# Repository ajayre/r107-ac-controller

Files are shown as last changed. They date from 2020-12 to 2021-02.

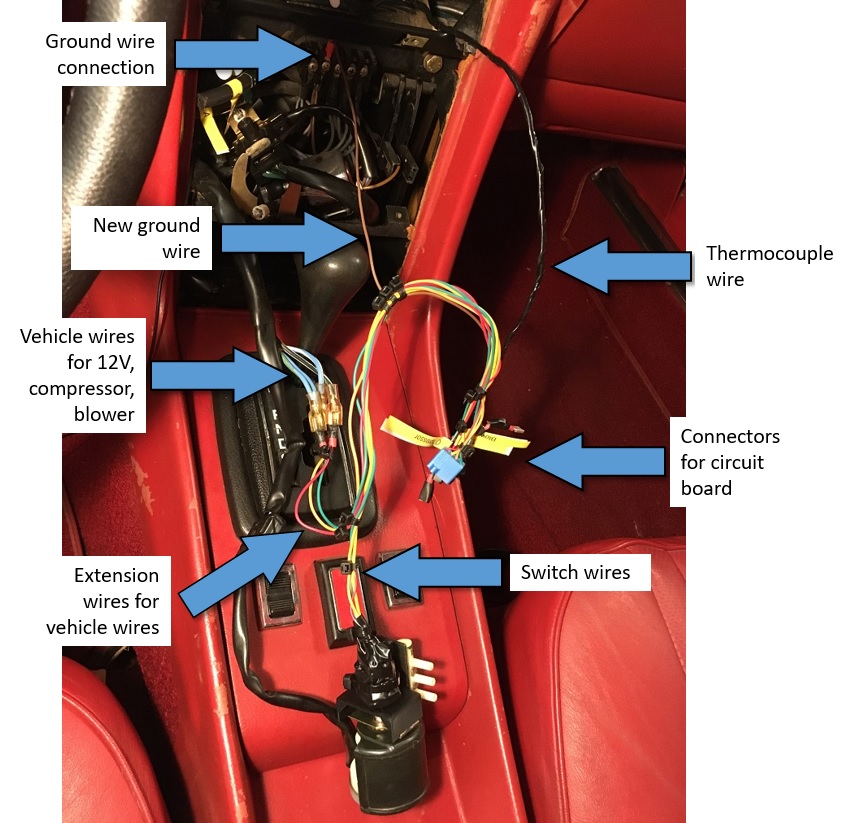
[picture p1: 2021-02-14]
Electronics/Car Wiring Annotated.jpg

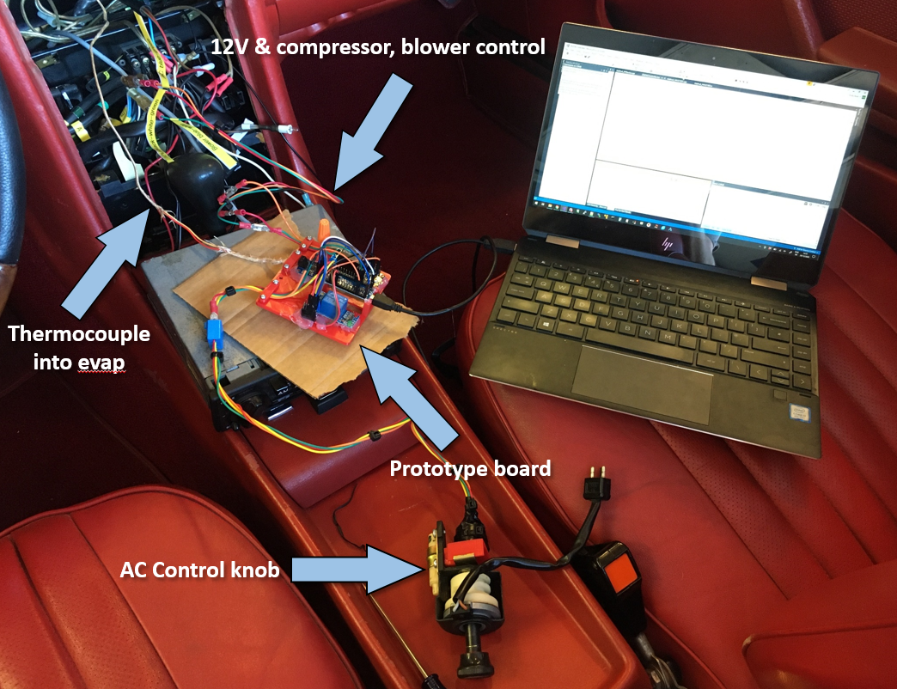
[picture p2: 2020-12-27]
Electronics/Prototyping/Prototype Setup.png

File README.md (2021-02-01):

# R107/C107 Air Conditioning Controller

This is an AC controller for the original Mercedes-Benz R107/C107 manual climate control system. The original system is identified by four vertical levers.

The problem with the AC switch is the delicate capillary tube that senses the evaporator temperature. With age these become brittle and snap off while working on items in the central console. Once broken they are not repairable. Replacements are not available to purchase.

The aim of this project is to replace the Ranco electro-mechanical part of the AC switch with a modern electronic equivalent.

This work is copyright (C) Andrew Ayre 2021 and no commercial use is permitted.

USE AT YOUR OWN RISK. NO WARRANTY, EXPRESS OR IMPLIED.

## Prototype Hardware

The prototype uses the following hardware:

* Arduino Nano - https://www.arduino.cc/en/pmwiki.php?n=Main/ArduinoBoardNano
* Adafruit Thermocouple Amplifier MAX31855 breakout board - https://www.adafruit.com/product/269
* Adafruit Power Relay FeatherWing - https://www.adafruit.com/product/3191

## Development Tools

* Arduino IDE - https://www.arduino.cc/en/software
* Install Microsoft Visual Studio Community Edition 2017 - https://visualstudio.microsoft.com/vs/older-downloads/
* Install Visual Micro - https://marketplace.visualstudio.com/items?itemName=VisualMicro.ArduinoIDEforVisualStudio

## Custom Board

### Programming the Bootloader

Use the Arduino IDE, choose the ATmega328P and your ISP programmer (e.g. USBtinyISP). If you choose to power the board from the programmer then there is no need to provide power via USP or 12V. Connect to the six-pin ISP connector.

### Programming the Firmware

Set the target to 'ATmega328P (Arduino Nano)'.
Connect to the USB connector - it will appear on your PC as a COM port.
Remove the RUN jumper. Replace the jumper after programming.

### LED Operation

The LED will turn on when firmware execution starts. Note that there is a delay of around two or three seconds while the bootloader runs and the LED will be off during this time.

* LED off = power supply problem
* LED on solid = in the 'ready' state, waiting for AC to be turned on. Compressor and blower are off
* LED on with flash off every two seconds = hardware error or corrupted firmware
* LED continually flashing = error
* LED flashing twice = in the 'running' state, blower is on and compressor cycles as needed
* LED flashing three times = in the 'freeze protection' state, blower is on and compressor is off

### RUN Jumper

The RUN jumper should be inserted when the board is installed in a vehicle. It needs to be removed during programming. The purpose of the RUN jumper is to stop noise on the receive line from keeping the board in the bootloader mode and stopping firmware from executing.

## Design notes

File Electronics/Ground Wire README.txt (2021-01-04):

GROUND WIRE
===========

1. Take a length of 20 gauge brown stranded wire

2. At one end crimp a eyelet connector (M4 size?) 22 gauge (red) so it can attach to the screw terminals used for the console lights.

3. At the other end crimp a female quick disconnect connector 0.250" 22 gauge (red).

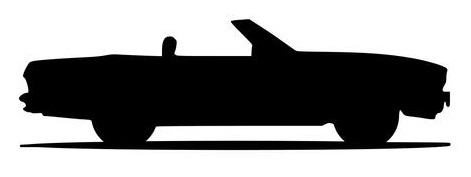
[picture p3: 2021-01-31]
Electronics/PCB/R107Silhouette.jpg

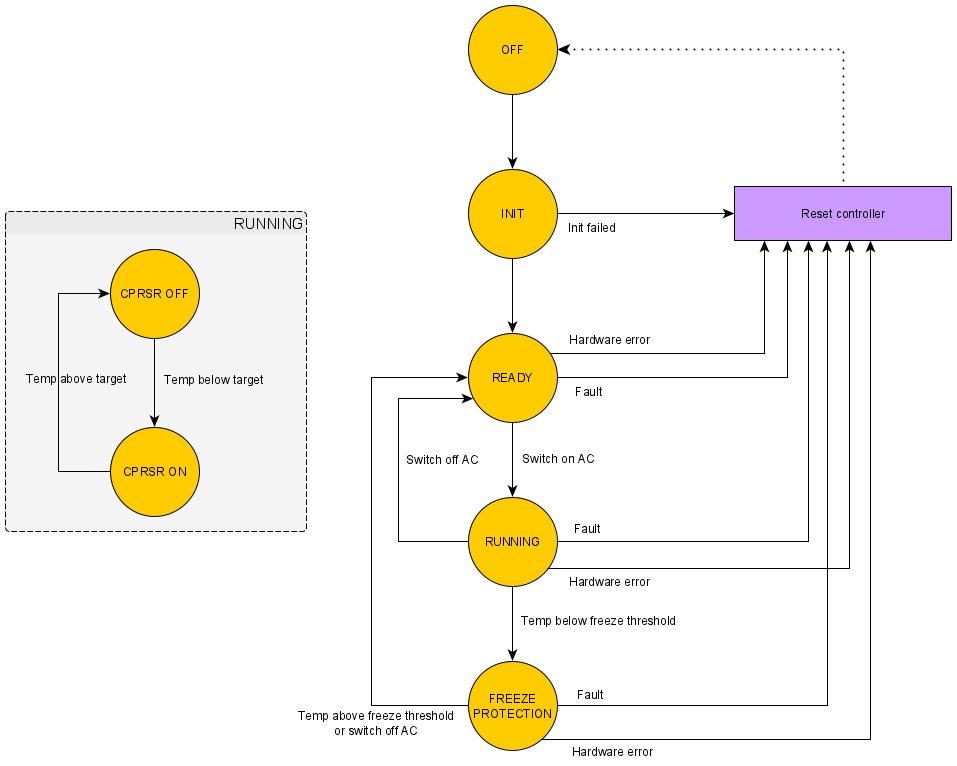
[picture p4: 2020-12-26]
Firmware/Design Documents/State Machine.png

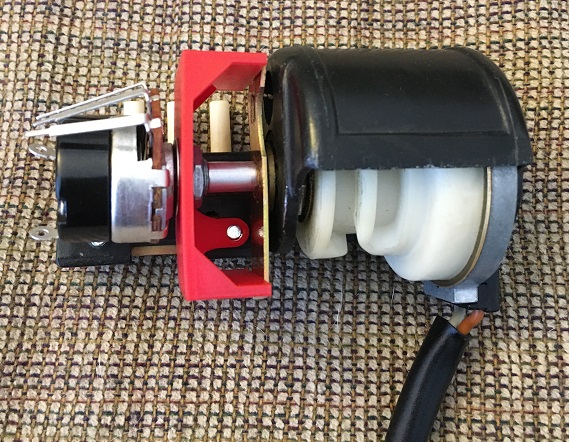
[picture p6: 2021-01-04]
Electronics/Control Knob/Pot.jpg

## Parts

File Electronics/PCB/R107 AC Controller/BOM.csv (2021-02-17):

Manufacturer Part Number | Manufacturer | Digi-Key Part Number | Quantity | Description
690-005-299-043 | EDAC Inc. | 151-1206-1-ND | 1 | CONN RCPT USB2.0 MINI B SMD R/A
ECS-160-18-5PX-TR | ECS Inc. | XC2081CT-ND | 1 | CRYSTAL 16.0000MHZ 18PF SMD
EEE-HA1V4R7R | Panasonic Electronic Components | PCE4248CT-ND | 2 | CAP ALUM 4.7UF 20% 35V SMD
EEE-FK1C681P | Panasonic Electronic Components | PCE3794CT-ND | 1 | CAP ALUM 680UF 20% 16V SMD
EEE-1VA100WR | Panasonic Electronic Components | PCE3948CT-ND | 2 | CAP ALUM 10UF 20% 35V SMD
EEE-FK1C221P | Panasonic Electronic Components | PCE3787CT-ND | 1 | CAP ALUM 220UF 20% 16V SMD
G5LE-14 DC5 | Omron Electronics Inc-EMC Div | Z1011-ND | 2 | RELAY GEN PURPOSE SPDT 10A 5V
MMBT2222ALT1G | ON Semiconductor | MMBT2222ALT1GOSCT-ND | 2 | TRANS NPN 40V 600MA SOT23
ATMEGA328P-AUR | Microchip Technology | ATMEGA328P-AURCT-ND | 1 | IC MCU 8BIT 32KB FLASH 32TQFP
LM2596S-5.0/NOPB | Texas Instruments | LM2596S-5.0/NOPB-ND | 1 | IC REG BUCK 5V 3A TO263-5
MAX31855KASA+T | Maxim Integrated | MAX31855KASA+TCT-ND | 1 | IC CONV THERMOCOUPLE-DGTL SOIC
FT232RL-REEL | FTDI, Future Technology Devices International Ltd | 768-1007-1-ND | 1 | IC USB FS SERIAL UART 28-SSOP
LS T67K-J1L2-1-Z | OSRAM Opto Semiconductors Inc. | 475-2516-1-ND | 1 | LED RED CLEAR 2PLCC SMD
BLM21AG471SH1D | Murata Electronics | 490-11039-1-ND | 2 | FERRITE BEAD 470 OHM 0805 1LN
7804 | Keystone Electronics | 36-7804-ND | 1 | CONN QC TAB 0.250 SOLDER
7802 | Keystone Electronics | 36-7802-ND | 3 | CONN QC TAB 0.250 SOLDER
CL21B104KBCNNNC | Samsung Electro-Mechanics | 1276-1003-1-ND | 4 | CAP CER 0.1UF 50V X7R 0805
CL21B105KOFNNNG | Samsung Electro-Mechanics | 1276-6471-1-ND | 2 | CAP CER 1UF 16V X7R 0805
08055A180JAT2A | AVX Corporation | 478-1307-1-ND | 2 | CAP CER 18PF 50V C0G/NP0 0805
CL21B103KBANNNC | Samsung Electro-Mechanics | 1276-1015-1-ND | 1 | CAP CER 10000PF 50V X7R 0805
MMSD4148T1G | ON Semiconductor | MMSD4148T1GOSCT-ND | 4 | DIODE GEN PURP 100V 200MA SOD123
RNCP0805FTD1K00 | Stackpole Electronics Inc | RNCP0805FTD1K00CT-ND | 7 | RES 1K OHM 1% 1/4W 0805
RNCP0805FTD10K0 | Stackpole Electronics Inc | RNCP0805FTD10K0CT-ND | 4 | RES 10K OHM 1% 1/4W 0805
B360A-13-F | Diodes Incorporated | B360A-FDICT-ND | 1 | DIODE SCHOTTKY 60V 3A SMA
MBR0520LT1G | ON Semiconductor | MBR0520LT1GOSCT-ND | 1 | DIODE SCHOTTKY 20V 500MA SOD123

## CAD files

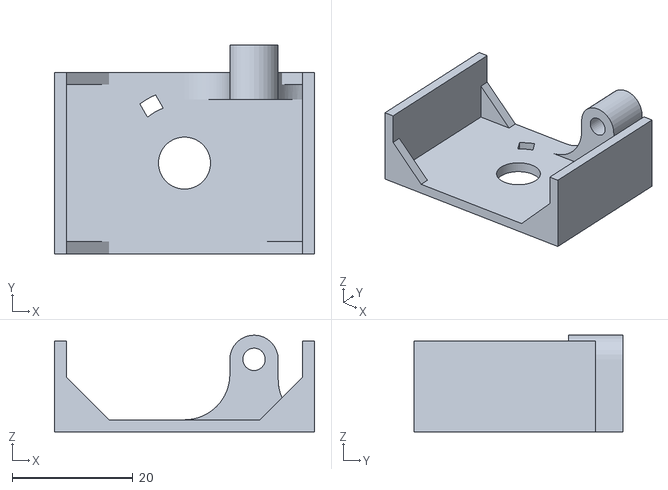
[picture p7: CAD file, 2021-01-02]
Mechanical/CAD/Pot Bracket.stl
43.0 x 34.5 x 16.0

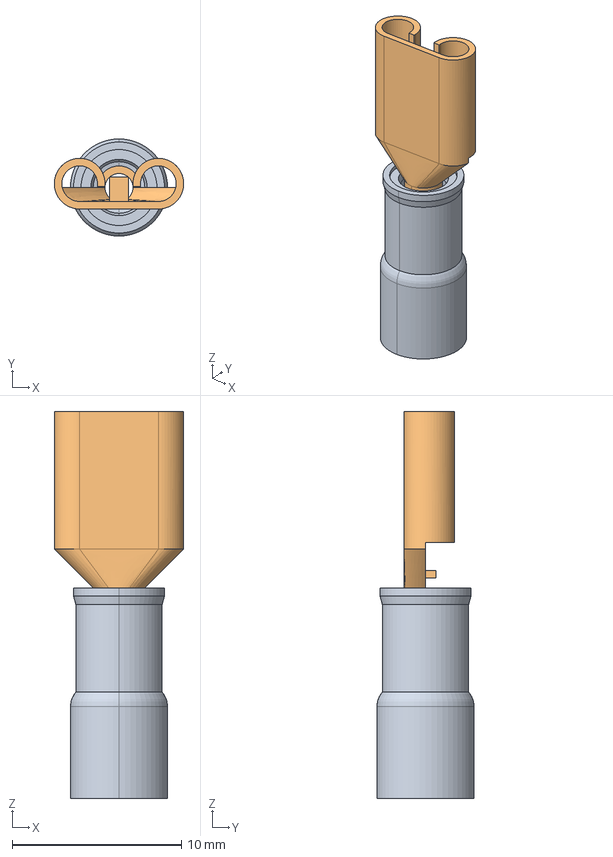
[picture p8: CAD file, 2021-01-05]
Mechanical/Case/c-0640903-81-j1-3d.stp
7.64 x 5.74 x 22.9 mm

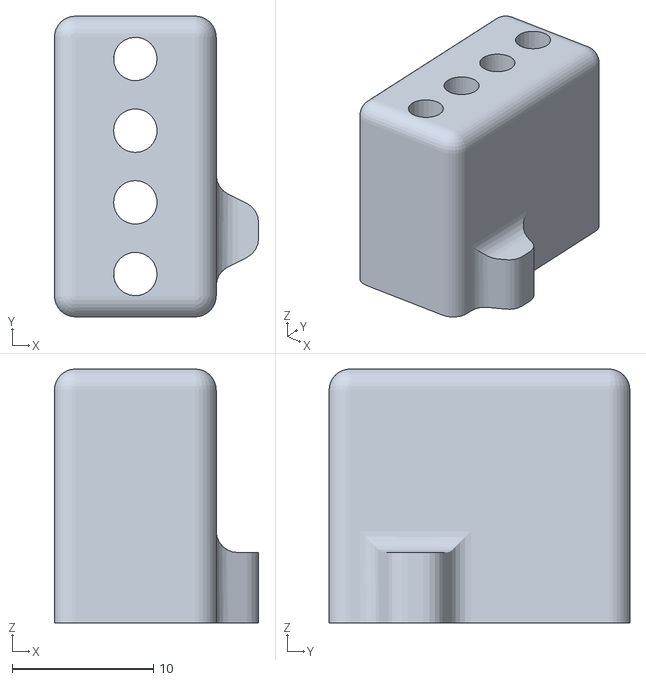
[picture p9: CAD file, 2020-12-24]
Mechanical/CAD/Four Pin Connector.stl
14.5 x 21.3 x 18.0

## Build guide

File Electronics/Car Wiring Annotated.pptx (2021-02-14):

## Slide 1

Ground wire connection

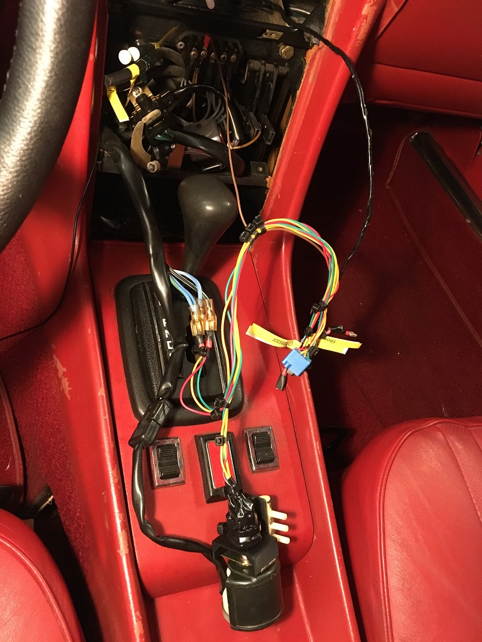
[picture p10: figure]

New ground wire

Vehicle wires for 12V, compressor, blower

Thermocouple wire

Switch wires

Connectors for circuit board

Extension wires for vehicle wires

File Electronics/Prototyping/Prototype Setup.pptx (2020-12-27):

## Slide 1

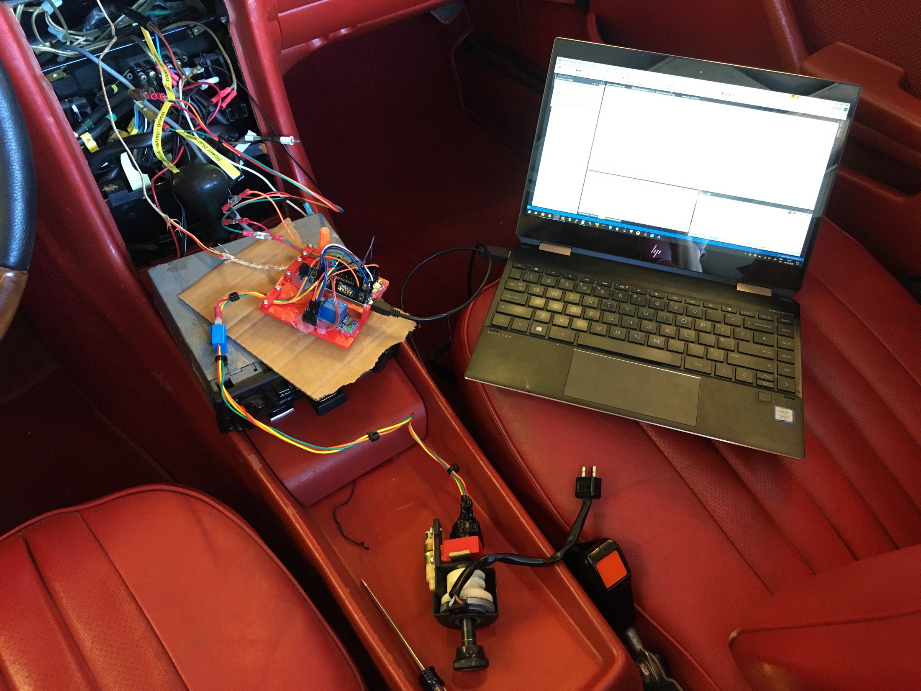
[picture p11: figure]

12V & compressor, blower control

Thermocouple
into evap

Prototype board

AC Control knob

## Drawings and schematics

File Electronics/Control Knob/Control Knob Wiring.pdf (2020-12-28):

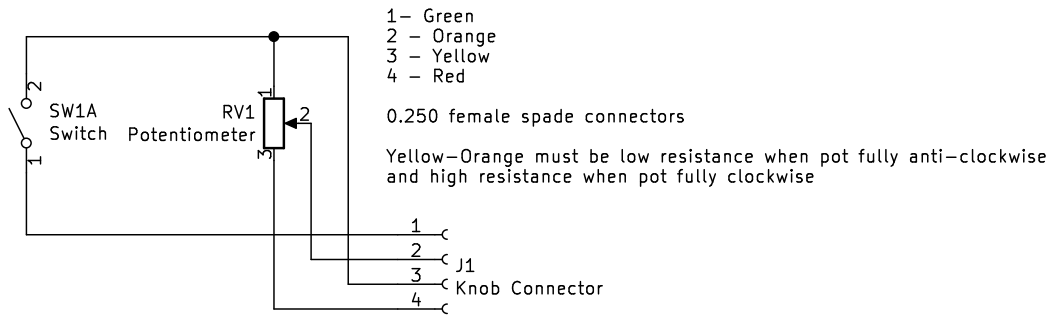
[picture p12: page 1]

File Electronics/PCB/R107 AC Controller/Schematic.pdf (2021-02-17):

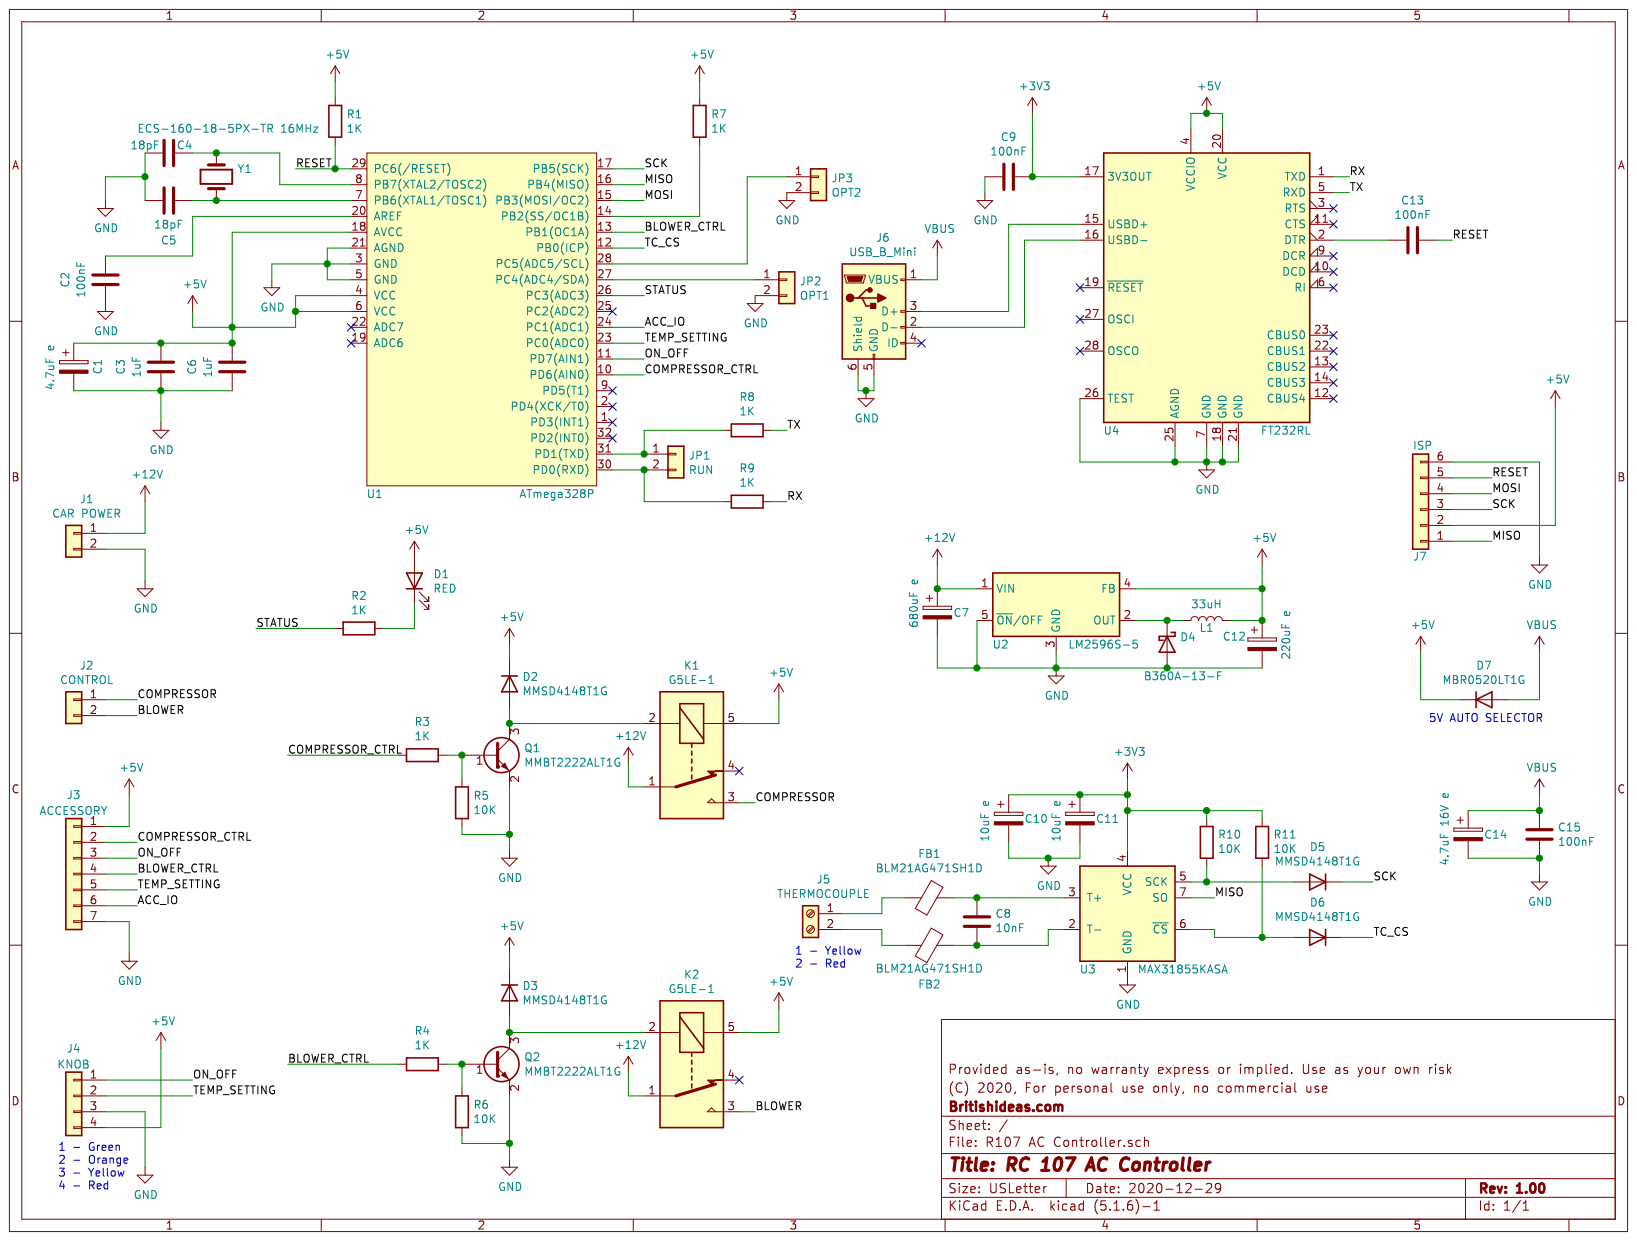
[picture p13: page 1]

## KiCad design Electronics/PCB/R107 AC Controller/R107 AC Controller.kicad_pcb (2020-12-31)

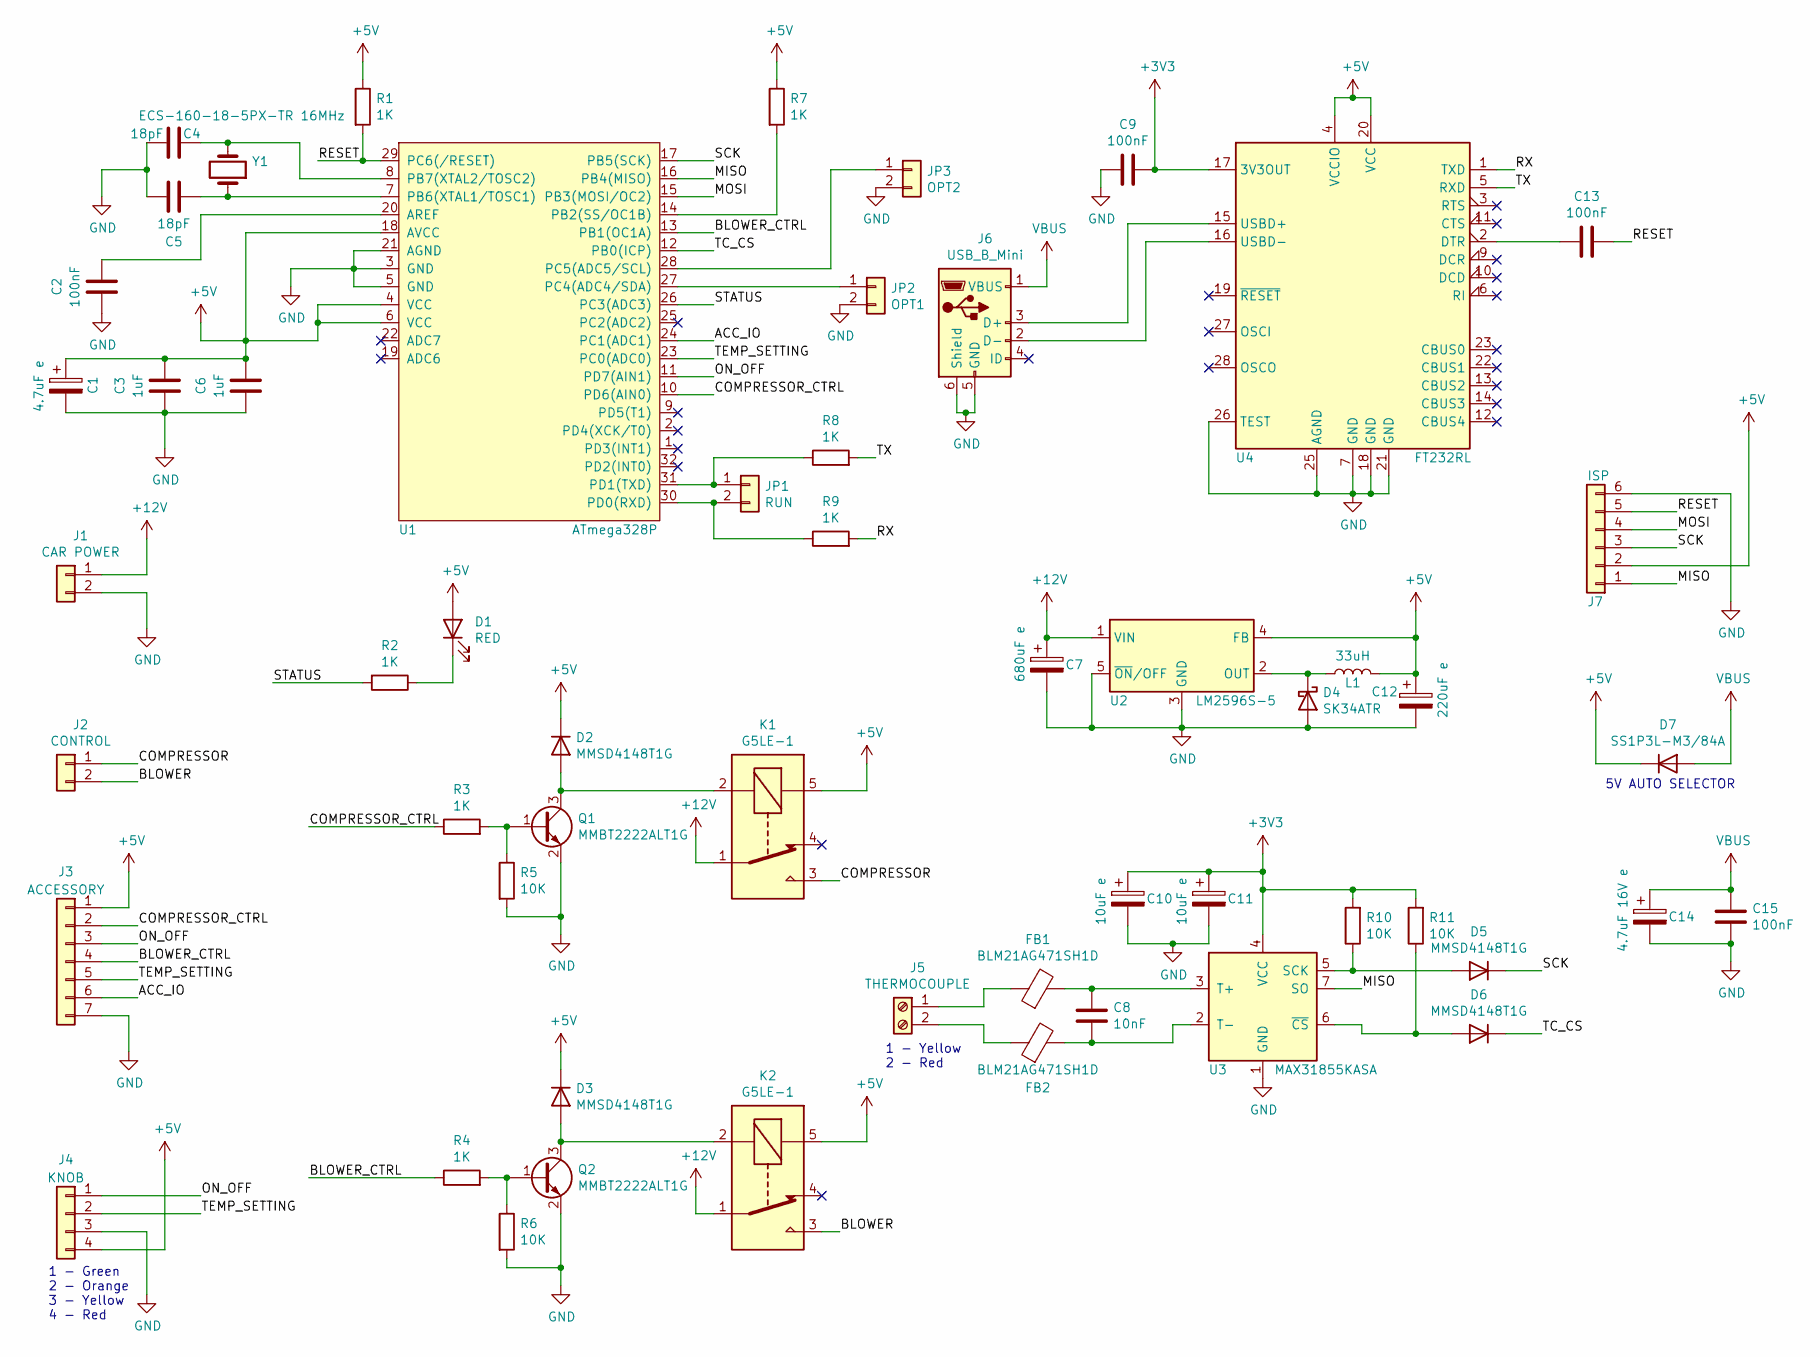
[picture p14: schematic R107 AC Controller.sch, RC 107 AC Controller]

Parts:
C1: 4.7uF e; CP_Elec_4x5.8
C2, C9, C13, C15: 100nF; C_0805_2012Metric
C3, C6: 1uF; C_0805_2012Metric
C4, C5: 18pF; C_0805_2012Metric
C7: 680uF e; CP_Elec_10x10.5
C8: 10nF; C_0805_2012Metric
C10, C11: 10uF e; CP_Elec_4x5.4
C12: 220uF e; CP_Elec_8x6.5
C14: 4.7uF 16V e; CP_Elec_4x5.8
D1: RED; LED_PLCC-2
D2, D3, D5, D6: MMSD4148T1G; D_SOD-123
D4: SK34ATR; D_SMA
D7: SS1P3L-M3/84A; SMP_DO-220AA
FB1, FB2: BLM21AG471SH1D; L_0805_2012Metric
J1: CAR POWER; Keystone_SturdiMount_TabConnector_1x2
J2: CONTROL; Keystone_SturdiMount_TabConnector_1x2
J3: ACCESSORY; PinHeader_1x07_P2.54mm_Vertical
J4: KNOB; Keystone_SturdiMount_TabConnector_1x4
J5: THERMOCOUPLE; TerminalBlock_TE_282834-2_1x02_P2.54mm_Horizontal
J6: USB_B_Mini; USB_Mini-B_Wuerth_65100516121_Horizontal
J7: ISP; PinHeader_2x03_P2.54mm_Vertical
JP1: RUN; PinHeader_1x02_P2.54mm_Vertical
JP2: OPT1; PinHeader_1x02_P2.54mm_Vertical
JP3: OPT2; PinHeader_1x02_P2.54mm_Vertical
K1, K2: G5LE-1; Relay_SPDT_Omron-G5LE-1
L1: 33uH; Chilisin_Power_Inductor_AWVS_808040
Q1, Q2: MMBT2222ALT1G; SOT-23
R1, R2, R3, R4, R7, R8, R9: 1K; R_0805_2012Metric
R5, R6, R10, R11: 10K; R_0805_2012Metric
U1: ATmega328P; LQFP-32_7x7mm_P0.8mm
U2: LM2596S-5; TO-263-5_TabPin3
U3: MAX31855KASA; SOIC-8_3.9x4.9mm_P1.27mm
U4: FT232RL; SSOP-28_5.3x10.2mm_P0.65mm
Y1: ECS-160-18-5PX-TR 16MHz; HC-49_US

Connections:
+3V3: C9.1, C10.1, C11.1, R10.2, R11.2, U3.4 (VCC), U4.17 (3V3OUT)
+5V: C1.1, C3.1, C6.1, C12.1, D1.2 (A), D2.1 (K), D3.1 (K), D7.1 (K), J3.1, J4.4, J7.2, K1.5, K2.5, L1.2, R1.1, R7.1, U1.4 (VCC), U1.6 (VCC), U1.18 (AVCC), U2.4 (FB), U4.4 (VCCIO), U4.20 (VCC)
+12V: C7.1, J1.1, K1.1, K2.1, U2.1 (VIN)
/ACC_IO: J3.6, U1.24 (PC1(ADC1))
/BLOWER: J2.2, K2.3
/BLOWER_CTRL: J3.4, R4.1, U1.13 (PB1(OC1A))
/COMPRESSOR: J2.1, K1.3
/COMPRESSOR_CTRL: J3.2, R3.1, U1.10 (PD6(AIN0))
/MISO: J7.1, U1.16 (PB4(MISO)), U3.7 (SO)
/MOSI: J7.4, U1.15 (PB3(MOSI/OC2))
/ON_OFF: J3.3, J4.1, U1.11 (PD7(AIN1))
/RESET: C13.1, J7.5, R1.2, U1.29 (PC6(/RESET))
/RX: R9.2, U4.1 (TXD)
/SCK: D5.1 (K), J7.3, U1.17 (PB5(SCK))
/STATUS: R2.2, U1.26 (PC3(ADC3))
/TC_CS: D6.1 (K), U1.12 (PB0(ICP))
/TEMP_SETTING: J3.5, J4.2, U1.23 (PC0(ADC0))
/TX: R8.2, U4.5 (RXD)
GND: C1.2, C2.2, C3.2, C4.2, C5.1, C6.2, C7.2, C9.2, C10.2, C11.2, C12.2, C14.2, C15.2, D4.2 (A), J1.2, J3.7, J4.3, J6.5 (GND), J6.6 (Shield), J7.6, JP2.2, JP3.2, Q1.2 (E), Q2.2 (E), R5.2, R6.2, U1.3 (GND), U1.5 (GND), U1.21 (AGND), U2.3 (GND), U2.5 (~ON~/OFF), U3.1 (GND), U4.7 (GND), U4.18 (GND), U4.21 (GND), U4.25 (AGND), U4.26 (TEST)
unnamed: C2.1, U1.20 (AREF)
unnamed: C4.1, U1.8 (PB7(XTAL2/TOSC2)), Y1.2
unnamed: C5.2, U1.7 (PB6(XTAL1/TOSC1)), Y1.1
unnamed: C8.1, FB2.2, U3.2 (T-)
unnamed: C8.2, FB1.2, U3.3 (T+)
unnamed: C13.2, U4.2 (DTR)
unnamed: D1.1 (K), R2.1
unnamed: D2.2 (A), K1.2, Q1.3 (C)
unnamed: D3.2 (A), K2.2, Q2.3 (C)
unnamed: D4.1 (K), L1.1, U2.2 (OUT)
unnamed: D5.2 (A), R10.1, U3.5 (SCK)
unnamed: D6.2 (A), R11.1, U3.6 (~CS~)
unnamed: FB1.1, J5.1
unnamed: FB2.1, J5.2
unnamed: J6.2 (D-), U4.16 (USBD-)
unnamed: J6.3 (D+), U4.15 (USBD+)
unnamed: JP1.1, R8.1, U1.31 (PD1(TXD))
unnamed: JP1.2, R9.1, U1.30 (PD0(RXD))
unnamed: JP2.1, U1.27 (PC4(ADC4/SDA))
unnamed: JP3.1, U1.28 (PC5(ADC5/SCL))
unnamed: Q1.1 (B), R3.2, R5.1
unnamed: Q2.1 (B), R4.2, R6.1
unnamed: R7.2, U1.14 (PB2(SS/OC1B))
VBUS: C14.1, C15.1, D7.2 (A), J6.1 (VBUS)

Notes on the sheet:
5V AUTO SELECTOR
1 - Green 2 - Orange 3 - Yellow 4 - Red
1 - Yellow 2 - Red

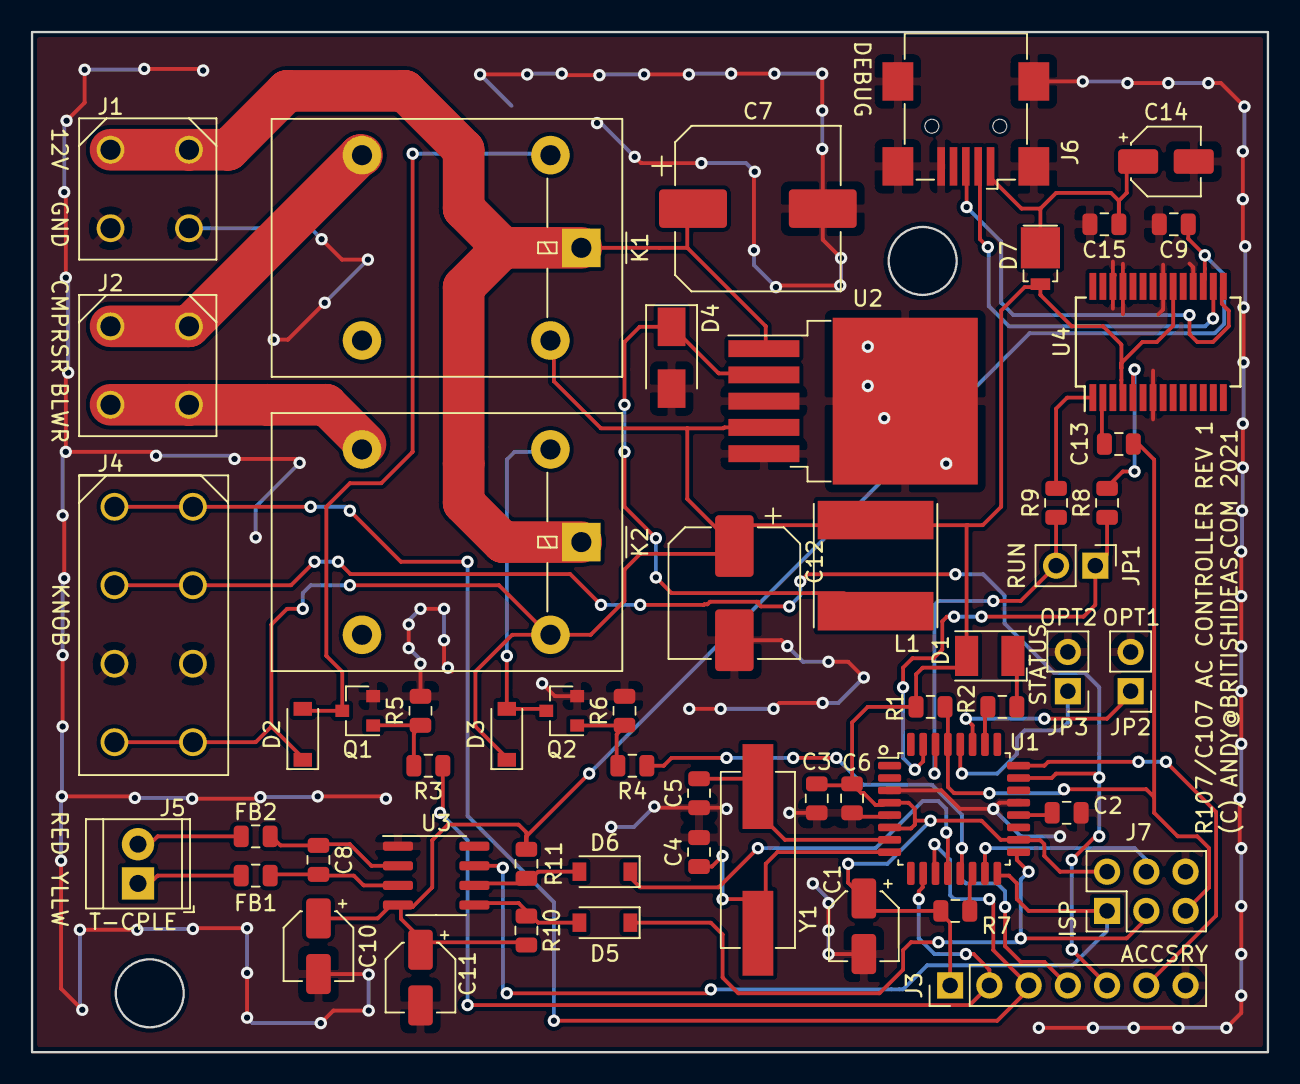
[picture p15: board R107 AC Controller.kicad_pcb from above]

Board: 2 copper layers, 80.0 x 66.0 mm, 55 parts (0 on the bottom side), 43 nets.

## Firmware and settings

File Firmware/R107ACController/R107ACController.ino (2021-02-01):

// R107/C107 AC Controller (manual climate control)
// (C) Andy Ayre, 2021, all rights reserved, no commercial usage
// https://github.com/ajayre/r107-ac-controller
// Outputs to serial port at 57,600 baud

#include "src/Adafruit-MAX31855/Adafruit_MAX31855.h"
#include <avr/wdt.h>

// the version of this firmware
#define VERSION "1.00"

// define to 1 to simulate ac instead of reading thermocouple
#define SIMULATE_AC 0

// logic
#define FALSE (0)
#define TRUE (!FALSE)

// minimum evap temperature in celcius
// below this the freeze protection will start
#define MINIMUM_TEMPERATURE 2.0F
// the number of degrees in celcius the evap temp has to rise before
// exiting freeze protection
#define FREEZEPROTECTION_HYSTERESIS 1.0F
// the number of degrees in celcius the eval temp has to rise before
// turning compressor back on after reaching target
// larger value = worse performance of system
// smaller value = more cycling of compressor on/off when at target
#define TEMP_HYSTERESIS 1.0F
// size of temperature range controllable by user, in degrees celcius
#define TEMP_RANGE 15.0F

// pin to control the compressor
#define COMPRESSOR      6    // D6
// pin for on/off switch
#define CONTROL_SWITCH  7    // D7
// thermocouple chip select (uses hardware SPI)
#define CS_THERMOCOUPLE 8    // D8
// pin to control the blower motor
#define BLOWER_MOTOR    9    // D9
// pin for temperature control (analog)
#define TEMP_SETTING    A0
// pin for status LED
#define STATUS_LED      A3
// pin for opt 1
#define OPT1            A4
// pin for opt 2
#define OPT2            A5

// thermocouple errors
#define THERMOCOUPLE_ERROR_SCV 0x04 // short circuit to vcc
#define THERMOCOUPLE_ERROR_SCG 0x02 // short circuit to ground
#define THERMOCOUPLE_ERROR_OC  0x01 // open connection

// status LED control
#define STATUS_LED_ON  digitalWrite(STATUS_LED, LOW)
#define STATUS_LED_OFF digitalWrite(STATUS_LED, HIGH);
#define IS_STATUS_LED_ON (digitalRead(STATUS_LED) == 1 ? FALSE : TRUE)

// blower control macros (connect to NO on relay)
#define BLOWER_OFF digitalWrite(BLOWER_MOTOR, LOW); Serial.println("Blower off");
#define BLOWER_ON  digitalWrite(BLOWER_MOTOR, HIGH); Serial.println("Blower on");
#define IS_BLOWER_ON digitalRead(BLOWER_MOTOR)

// compressor control macros (connect to NO on relay)
#define COMPRESSOR_OFF digitalWrite(COMPRESSOR, LOW); Serial.println("Compressor off")
#define COMPRESSOR_ON  digitalWrite(COMPRESSOR, HIGH); Serial.println("Compressor on")
#define IS_COMPRESSOR_ON digitalRead(COMPRESSOR)

// control switch macro
// returns 0 for off, 1 for on
#define GET_CONTROL_SWITCH (!(digitalRead(CONTROL_SWITCH) & 0x01))

// temp setting macro
// returns 0 = min, 1023 = max
#define RAW_TEMP_SETTING analogRead(TEMP_SETTING)
// raw temp setting where switch moves from fresh air to inside air
#define RAW_INSIDE_AIR_THRESHOLD 800
// scaled temp setting threshold
#define INSIDE_AIR_THRESHOLD (RAW_INSIDE_AIR_THRESHOLD / 1023.0F * 100.0F)

// minimum on or off time in milliseconds
#define LED_PERIOD 200
// time between patterns as a multiple of LED_PERIOD
#define LED_PATTERN_OFF_TIME 4

// pattern to show on LED in the various state machine states
#define LED_PATTERN_RUNNING          2
#define LED_PATTERN_FREEZEPROTECTION 3

// time between updates of debug output in milliseconds
#define DEBUG_OUTPUT_PERIOD 500

// number of evap temperature readings to use for averaging
// larger number = more smoothing, lower number = faster response to changes
#define AVERAGING_NUM_EVAP_READINGS 256

// never use simulation for release builds
#if _DEBUG == 0
#undef SIMULATE_AC
#define SIMULATE_AC 0
#endif // _DEBUG == 0

// ac state machine states
typedef enum _acstates
{
  OFF,
  INIT,
  READY,
  RUNNING,
  FREEZEPROTECTION
} ACSTATE;

// modes of operation for the LED
typedef enum _ledmodes
{
  LED_Mode_Off,
  LED_Mode_On,
  LED_Mode_Error,
  LED_Mode_Pattern
} LEDMODES;

// the states used to flash patterns on the LED
typedef enum _ledpatternstates
{
  LED_Pattern_Flashing,
  LED_Pattern_Paused
} LEDPATTERNSTATES;

// access to thermocouple
static Adafruit_MAX31855 Thermocouple(CS_THERMOCOUPLE);
// current ac state
static ACSTATE ACState = OFF;

// timestamp for debug output
static unsigned long NextDebugOutputTime;

// averaging of temperature
static double EvapTemperatureAverageN;
static int EvapTemperatureValid;
static int EvapTemperatureReadings;

// LED handling
static LEDMODES LEDMode;
static unsigned long LEDNextTime;
static int LEDPatternCounter;
static LEDPATTERNSTATES LEDPatternState;
static int LEDPatternNumber;

#if SIMULATE_AC == 1
static unsigned long SimulationTimestamp = 0;
static double SimulatedTemp = -1;
static double GetSimulatedTemperature
  (
  double AmbientTemperature
  )
{
  // don't do anything until one second has passed
  if (millis() - SimulationTimestamp < 1000)
  {
    return;
  }

  SimulationTimestamp = millis();

  // set starting temp for simulation
  if (SimulatedTemp < 0) SimulatedTemp = AmbientTemperature;

  // if compressor is on then decrease temp 6 deg C per min
  if (IS_COMPRESSOR_ON)
  {
    SimulatedTemp -= 0.1;
    if (SimulatedTemp < 0) SimulatedTemp = 0;
  }
  // if compressor is off then increase temp 6 deg C per min
  else
  {
    SimulatedTemp += 0.1;
    if (SimulatedTemp > AmbientTemperature) SimulatedTemp = AmbientTemperature;
  }

  return SimulatedTemp;
}
#endif // SIMULATE_AC == 1

// Starts flashing a pattern on the LED
static void EnableLEDPattern
  (
  int PatternNumber                  // number of flashes before pausing
  )
{
  LEDMode = LED_Mode_Pattern;
  LEDNextTime = GetTime() + LED_PERIOD;
  LEDPatternCounter = 0;
  LEDPatternState = LED_Pattern_Flashing;
  LEDPatternNumber = PatternNumber;
  STATUS_LED_OFF;
}

// Gets the current time in milliseconds since last power on
static unsigned long GetTime
  (
  void
  )
{
  return millis();
}

// Checks if a timestamp is in the past, handles 32-bit timer overflow
static uint8_t IsTimeExpired
  (
  unsigned long timestamp            // timestamp to check
  )
{
  unsigned long time_now;

  time_now = millis();
  if (time_now >= timestamp)
  {
    if ((time_now - timestamp) < 0x80000000)
      return 1;
    else
      return 0;
  }
  else
  {
    if ((timestamp - time_now) >= 0x80000000)
      return 1;
    else
      return 0;
  }
}

// Call frequently to update the LED
static void LEDHandler
  (
  void
  )
{
  if (IsTimeExpired(LEDNextTime))
  {
    switch (LEDMode)
    {
      // turn LED off
    case LED_Mode_Off:
      STATUS_LED_OFF;
      break;

      // turn LED on
    case LED_Mode_On:
      STATUS_LED_ON;
      break;

      // show the error state on the LED
    case LED_Mode_Error:
      if (IS_STATUS_LED_ON)
      {
        STATUS_LED_OFF;
      }
      else
      {
        STATUS_LED_ON;
      }
      break;

      // show a specific pattern on the LED
    case LED_Mode_Pattern:
      switch (LEDPatternState)
      {
      case LED_Pattern_Flashing:
        if (IS_STATUS_LED_ON)
        {
          STATUS_LED_OFF;
        }
        else
        {
          STATUS_LED_ON;
          if (++LEDPatternCounter == LEDPatternNumber)
          {
            LEDPatternState = LED_Pattern_Paused;
            LEDPatternCounter = 0;
          }
        }
        break;

      case LED_Pattern_Paused:
        STATUS_LED_OFF;
        if (++LEDPatternCounter == LED_PATTERN_OFF_TIME)
        {
          LEDPatternState = LED_Pattern_Flashing;
          LEDPatternCounter = 0;
        }
        break;
      }
      break;
    }

    LEDNextTime = GetTime() + LED_PERIOD;
  }
}

// calculates the target evap temperature based on the current setting
// and measurements
// note - if TempSetting is greater than INSIDE_AIR_THRESHOLD then the
// switch is in the 'inside' range
// returns the target evap temperature in degrees C
// note - return value must be at least MINIMUM_TEMPERATURE
static double GetTargetEvapTemperature
(
  double TempSetting,                           // user's temp setting 0 (min) -> 100 (max)
  double AmbientTemperature,                    // in degrees C, taken from behind dashboard, NOT equal to outside temp
  double EvapTemperature,                       // in degrees C
  int OutputDebugData                           // TRUE to allow output of debug data
  )
{
  if (OutputDebugData)
  {
    Serial.print("Knob setting % = ");
    Serial.print(TempSetting);
    if (TempSetting > INSIDE_AIR_THRESHOLD)
      Serial.println(" (inside)");
    else
      Serial.println(" (fresh air)");
  }

  // get controllable temperarure range
  double MinTemp = MINIMUM_TEMPERATURE;
  double MaxTemp = MinTemp + TEMP_RANGE;

  // scale the user's temperature setting over the min -> max range
  double TargetTemperature = MaxTemp - ((MaxTemp - MinTemp) * (TempSetting / 100.0));

  return TargetTemperature;
}

// the setup function runs once when you press reset or power the board
void setup
  (
  void
  )
{
  int opt1, opt2;

#if _DEBUG == 0
  // enable watchdog timer with two second timeout
  wdt_enable(WDTO_2S);
#endif

  // configure status LED and turn on
  pinMode(STATUS_LED, OUTPUT);
  // turn LED on
  LEDMode = LED_Mode_On;

  // start serial output
  Serial.begin(57600);
  while (!Serial) delay(1);
  Serial.flush();

  // print banner
  Serial.println("R107 C107 AC Controller (C) Andy Ayre 2021");
  Serial.println("andy@britishideas.com");
  Serial.print("Version ");
  Serial.println(VERSION);
  Serial.println();

  // configure blower motor
  pinMode(BLOWER_MOTOR, OUTPUT);
  BLOWER_OFF;

  // configure compressor
  pinMode(COMPRESSOR, OUTPUT);
  COMPRESSOR_OFF;

  // configure control switch
  pinMode(CONTROL_SWITCH, INPUT_PULLUP);
  
  // configure and read options
  pinMode(OPT1, INPUT_PULLUP);
  pinMode(OPT2, INPUT_PULLUP);

  // read option pins, 0 = no jumper installed, 1 = jumper installed
  // default is no jumpers installed
  opt1 = digitalRead(OPT1) == 0 ? 1 : 0;
  opt2 = digitalRead(OPT2) == 0 ? 1 : 0;

  Serial.print("opt1="); Serial.print(opt1);
  Serial.print(", opt2="); Serial.println(opt2);

  wdt_reset();

  Serial.println("Init");
  ACState = INIT;

  // wait for thermocouple to become ready, comes from the adafruit example
  delay(500);

  wdt_reset();

  // start thermocouple
  if (!Thermocouple.begin())
  {
    Serial.println("Failed to initalize thermocouple");
    ACState = OFF;
    LEDMode = LED_Mode_Error;

    // wait for reset
    while (1);
  }

  wdt_reset();

  Serial.println("Ready");
  ACState = READY;
  LEDMode = LED_Mode_On;

  NextDebugOutputTime = GetTime() + DEBUG_OUTPUT_PERIOD;

  // no readings yet
  EvapTemperatureAverageN = 0;
  EvapTemperatureValid = FALSE;
  EvapTemperatureReadings = 0;
}

// the loop function runs over and over again until power down or reset
void loop
  (
  void
  )
{
  double AveragedEvapTemperature;
  int OutputDebugData = FALSE;

  // feed watchdog
  wdt_reset();

  // update LED state
  LEDHandler();

  // get temperature of cabin
  double AmbientTemperature = Thermocouple.readInternal();

  // get current evap temperature and check for fault
  double EvapTemperature;
#if SIMULATE_AC == 1
  EvapTemperature = GetSimulatedTemperature(AmbientTemperature);
#else
  EvapTemperature = Thermocouple.readCelsius();
#endif // SIMULATE_AC
  if (isnan(EvapTemperature))
  {
    Serial.print("Thermocouple fault ");
    uint8_t ThermocoupleError = Thermocouple.readError();
    if ((ThermocoupleError & THERMOCOUPLE_ERROR_SCV) == THERMOCOUPLE_ERROR_SCV) Serial.print("(short-circuit to Vcc)");
    if ((ThermocoupleError & THERMOCOUPLE_ERROR_SCG) == THERMOCOUPLE_ERROR_SCG) Serial.print("(short-circuit to Gnd)");
    if ((ThermocoupleError & THERMOCOUPLE_ERROR_OC)  == THERMOCOUPLE_ERROR_OC)  Serial.print("(open circuit)");
    Serial.println();

    COMPRESSOR_OFF;

    // wait for reset
    while (1);
  }

  // perform averaging
  if (EvapTemperatureReadings > 0)
  {
    EvapTemperatureAverageN = EvapTemperatureAverageN + EvapTemperature - (EvapTemperatureAverageN / AVERAGING_NUM_EVAP_READINGS);
    AveragedEvapTemperature = EvapTemperatureAverageN / AVERAGING_NUM_EVAP_READINGS;
  }
  else
  {
    // first sample, use it to set up the averaging data
    EvapTemperatureAverageN = EvapTemperature * AVERAGING_NUM_EVAP_READINGS;
  }
  if (!EvapTemperatureValid)
  {
    EvapTemperatureReadings++;
    if (EvapTemperatureReadings == AVERAGING_NUM_EVAP_READINGS)
    {
      EvapTemperatureValid = TRUE;
    }
  }

  // time to output some mode debug data?
  if (IsTimeExpired(NextDebugOutputTime))
  {
    OutputDebugData = TRUE;
    NextDebugOutputTime = GetTime() + DEBUG_OUTPUT_PERIOD;
  }
  else
  {
    OutputDebugData = FALSE;
  }

  // show current evap temperature
  if (OutputDebugData)
  {
    if (EvapTemperatureValid)
    {
      Serial.print("Evap = ");
      Serial.println(AveragedEvapTemperature);
    }
  }

  // check if SPI is non-functional
  if ((AmbientTemperature == 0) && (EvapTemperature == 0))
  {
    Serial.println("No response from thermocouple controller");
    ACState = OFF;
    COMPRESSOR_OFF;
    LEDMode = LED_Mode_Error;

    // wait for reset
    while (1);
  }

  // execute state machine
  switch (ACState)
  {
    case FREEZEPROTECTION:
      // if switch turned off then stop running
      if (!GET_CONTROL_SWITCH)
      {
        COMPRESSOR_OFF;
        BLOWER_OFF;
        Serial.println("Ready");
        ACState = READY;
        LEDMode = LED_Mode_On;
        break;
      }

      if (EvapTemperatureValid && (AveragedEvapTemperature >= (MINIMUM_TEMPERATURE + FREEZEPROTECTION_HYSTERESIS)))
      {
        Serial.println("Ready");
        ACState = READY;
        BLOWER_OFF;
        LEDMode = LED_Mode_On;
      }
      break;

    // do nothing in these states
    case OFF:
    case INIT:
      break;

    default:
      Serial.print("Unknown state ");
      Serial.println(ACState);
      // wait for reset
      while (1);
      break;

    case READY:
      // if switch turned on then ac now running
      if (GET_CONTROL_SWITCH)
      {
        ACState = RUNNING;
        Serial.println("Running");
        BLOWER_ON;
        EnableLEDPattern(LED_PATTERN_RUNNING);
      }
      break;

    case RUNNING:
      // if switch turned off then stop running
      if (!GET_CONTROL_SWITCH)
      {
        COMPRESSOR_OFF;
        BLOWER_OFF;
        Serial.println("Ready");
        ACState = READY;
        LEDMode = LED_Mode_On;
        break;
      }

      // check for minimum evap temo
      if (EvapTemperatureValid && (AveragedEvapTemperature <= MINIMUM_TEMPERATURE))
      {
        COMPRESSOR_OFF;
        Serial.println("Freeze protection");
        ACState = FREEZEPROTECTION;
        EnableLEDPattern(LED_PATTERN_FREEZEPROTECTION);
        break;
      }

      // get user's temp setting and scale to 0 -> 100
      double TempSetting = RAW_TEMP_SETTING;
      TempSetting = TempSetting / 1023 * 100;
      if (TempSetting < 0) TempSetting = 0;
      if (TempSetting > 100) TempSetting = 100;

      // get the target temperature in degrees C
      double TargetEvapTemperature = GetTargetEvapTemperature(TempSetting, AmbientTemperature, AveragedEvapTemperature, OutputDebugData);
      if (TargetEvapTemperature < MINIMUM_TEMPERATURE) TargetEvapTemperature = MINIMUM_TEMPERATURE;
      if (OutputDebugData)
      {
        Serial.print("Target temp = ");
        Serial.println(TargetEvapTemperature);
      }

      // turn compressor on or off as needed
      if (EvapTemperatureValid && (AveragedEvapTemperature <= TargetEvapTemperature))
      {
        if (IS_COMPRESSOR_ON) { COMPRESSOR_OFF; }
      }
      else if (EvapTemperatureValid && (AveragedEvapTemperature > (TargetEvapTemperature + TEMP_HYSTERESIS)))
      {
        if (!IS_COMPRESSOR_ON) { COMPRESSOR_ON; }
      }
      break;
  }

  wdt_reset();
}

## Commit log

2020-12-21 Added initial documents.
    [Pot Bracket.stl]
2020-12-21 Started code. Added Arduino nano pinout.
2020-12-23 Added more error checking.
    [R107ACController.ino]
2020-12-24 Added custom connectors.
    [Four Pin Connector.stl, One Pin Connector.stl, Two Pin Connector.stl]
2020-12-25 Added support for switch and pot. Removed unused connector.
    [Two Pin Connector.stl]
2020-12-25 Slowed down simulation. Bug fix to freeze protection.
    [R107ACController.ino]
2020-12-26 Added temperature control algorithm.
2020-12-26 Simplified target temperature calculation as the ambient temperature (outside air) is not known.
2020-12-27 First version of schematic diagram (requires KiCAD 5.1+). Added details of prototype setup.
    [R107 AC Controller.kicad_pcb, R107 AC Controller.sch]
2020-12-27 Updated schematic to fix mistakes.
    [R107 AC Controller.sch]
2020-12-28 Added details of how to modify and wire the control knob.
    [Control Knob.sch]
2020-12-28 Fixed mistake in control knob schematic.
    [Control Knob.sch]
2020-12-29 Updated schematic. Added BOM. Added more data sheets.
    [R107 AC Controller.sch]
2020-12-30 Improvements to schematic. Started work on PCB.
    [R107 AC Controller.kicad_pcb, R107 AC Controller.sch]
2020-12-31 Working on PCB. Added status LED and removed comms LEDs. Added jumper to reduce chances of noise on RX input keeping bootloader running.
    [R107 AC Controller.kicad_pcb, R107 AC Controller.sch]
2020-12-31 First attempt at PCB.
    [R107 AC Controller.kicad_pcb, R107 AC Controller.sch]
2020-12-31 Working on PCB. Adding 3D models. Moved silkscreen text away from vias where possible.
    [R107 AC Controller.kicad_pcb]
2020-12-31 Completed 3D models. Fixed mistake with footprint for L1 - was too small.
    [R107 AC Controller.kicad_pcb, R107 AC Controller.sch]
2020-12-31 Added render of board.
2020-12-31 Added CAD model of PCB for Alibre Design and STEP file. Added BOM.
    [BOM.csv]
2021-01-01 Added R107 silhouette to bottom of PCB.
2021-01-02 Added instructions for thermocouple. Updated pot bracket to work better with ABS plastic.
    [Pot Bracket.stl]
2021-01-03 Changed thermocouple connector to quick disconnect type.
    [BOM.csv, R107 AC Controller.sch]
2021-01-03 Added two pin connector for thermocouple. Removed one pin connector - not needed.
    [One Pin Connector.stl, Two Pin Connector.stl]
2021-01-04 Updated footprints for connectors. Generated gerber files.
    [R107 AC Controller-B_Cu.gbr, R107 AC Controller-B_Mask.gbr, R107 AC Controller-B_Paste.gbr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]
2021-01-04 Added PDF of schematic. Updated knob readme. Added pictures of knob.
2021-01-04 Removed two pin connector - not needed.
    [Two Pin Connector.stl]
2021-01-04 Added KiCAD custom PCB footprints.
2021-01-04 Updated 3D model of board.
2021-01-05 Working on case.
    [c-0640903-81-j1-3d.stp]
2021-01-12 Added readme for case.
2021-01-12 Updated case readme.
2021-01-15 Enlarge bolt holes.
2021-01-15 Removed edge chamfer from case - wasn't noticeable in the print and just helps to make the corners curl.
2021-01-23 Minor silkscreen tweak. Updated part name for diode.
    [R107 AC Controller.sch]
2021-01-24 Added additional datasheets. Updated schematic PDF.
2021-01-26 Regenerated BOM.
    [BOM.csv]
2021-01-31 Added support for LED.
2021-01-31 LED solid on when in ready state.
2021-01-31 Added PCB README. Changed part for diode D7.
    [BOM.csv, R107 AC Controller.sch]
2021-01-31 Updated BOM from Digikey.
    [BOM.csv]
2021-02-01 Added moving average for temperature.
2021-02-01 Cleanup of debug output. Reduced watchdog timeout to two seconds. Improved evap temperature averaging. Controller does not use evap temperature that has not been averaged (an initial set of samples c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
2021-02-08 Better fit for PCB.
2021-02-14 Added images of Car Wiring.jpg
2021-02-14 Added Powerpoint source file for wiring annotations.
2021-02-17 Updated PDF schematic and BOM.
    [BOM.csv]
2021-03-06 Updated to current ATmega328P
    [R107 AC Controller.sch]

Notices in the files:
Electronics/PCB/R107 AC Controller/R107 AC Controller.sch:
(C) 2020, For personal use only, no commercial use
